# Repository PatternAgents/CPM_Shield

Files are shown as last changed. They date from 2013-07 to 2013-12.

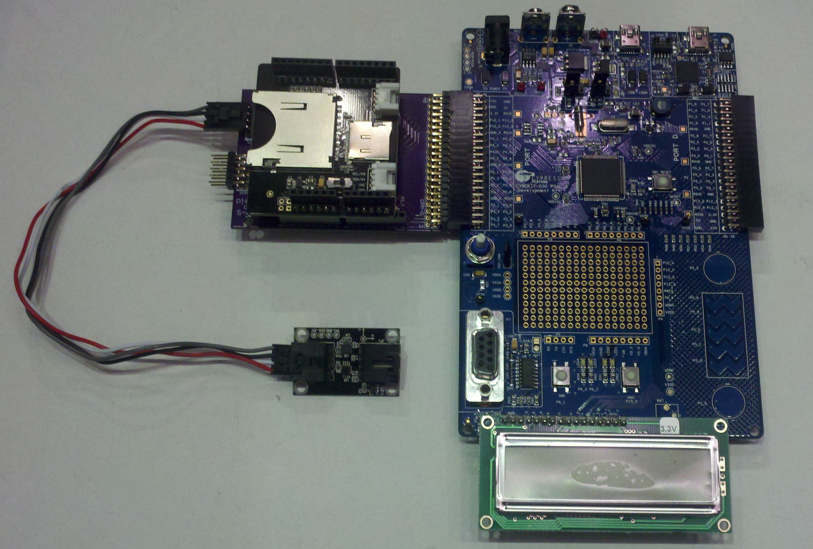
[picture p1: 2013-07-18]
CPM_Shield/images/final/hires/with_SD_shield.jpg

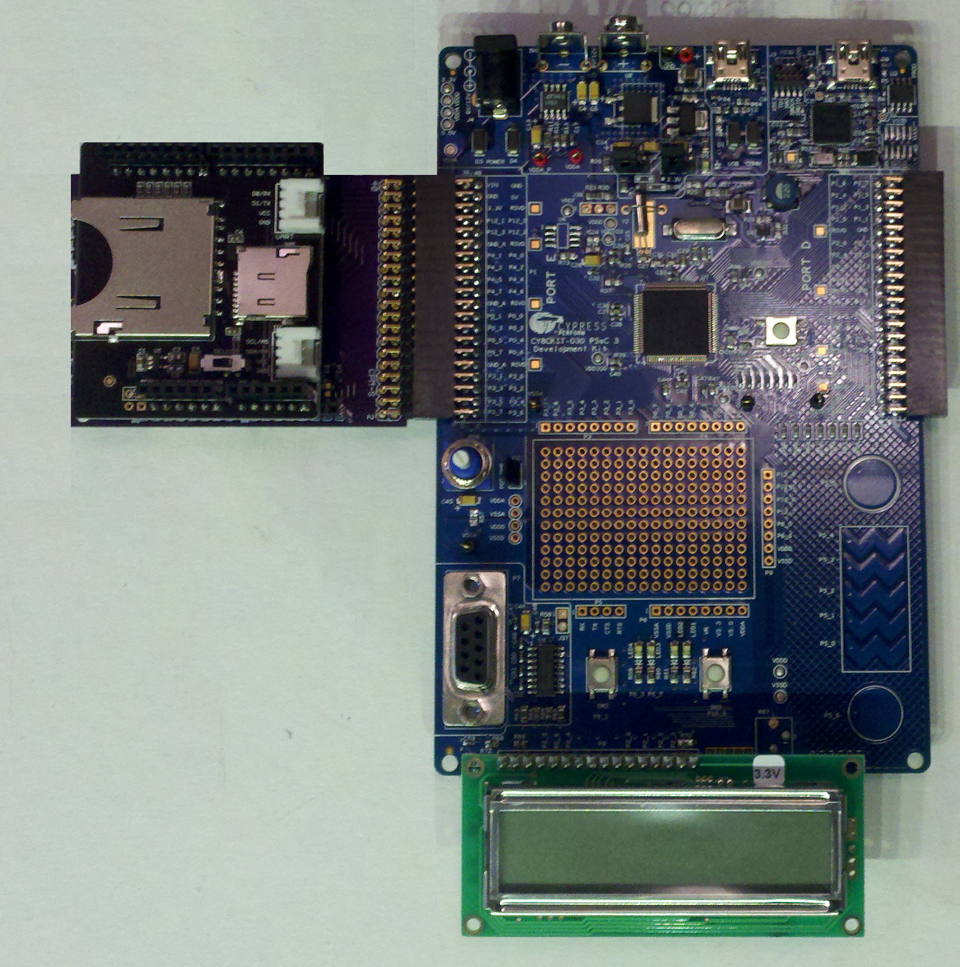
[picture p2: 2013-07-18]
CPM_Shield/images/final/hires/with_030_board_SD_CARD.jpg

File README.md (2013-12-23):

CPM Shield Adaptor
====================

PatternAgents CPM Shield Adaptor

[PatternAgents CPM Shield Adaptor  
*PatternAgents CPM Shield Adaptor*](http://www.patternagents.com/projects/CPM_Shield.html)

The "CPM Shield Adaptor" board is designed to enable Cypress PSoC development boards to utilize Arduino Shield peripherals.

The PatternAgents "CPM Shield Adaptor" board supports :

Cypress CY8CKIT-001 : (Supports up to three (3) "CPM Shield Adaptor")

Cypress CY8CKIT-030 : (Supports up to two (2) "CPM Shield Adaptor")

Cypress CY8CKIT-050 : (Supports up to two (2) "CPM Shield Adaptor")

Cypress CY3280-28xxx : (Supports one (1) "CPM Shield Adaptor")

Cypress CY3280-22x45 : (Supports one (1) "CPM Shield Adaptor")

(Not an Exhaustive list as more Cypress development boards are routinely released)

For information on the Arduino Shield Specification, see http://www.arduino.cc

[  
*Licensing CC BY-NC-SA 4.0*](http://creativecommons.org/licenses/by-nc-sa/4.0/)

PatternAgents uses the increasingly popular business model called "Dual Licensing" 
in which both the open source software distribution mechanism and traditional commercial software distribution models are combined.

Open Source Projects:        

If you are developing and distributing open source applications under the Creative Commons CC BY-NC-SA 4.0, 
as published by the Creative Commons Foundation, then you are free to use the PatternAgents hardware/software under the CC BY-NC-SA 4.0 license. 
Please note that CC BY-NC-SA 4.0 requires that all modifications to the original code as well as all Derivative Works 
must also be released under the terms of the CC BY-NC-SA 4.0 license.

Closed Source Projects:

If you are developing and distributing traditional closed source or commercial applications, 
you must purchase a PatternAgents commercial use license, 
which is specifically designed for users interested in retaining the proprietary status of their designs and code. 
All PatternAgents commercial licenses expressly supersede the CC BY-NC-SA 4.0 license. 
This means that when you license the PatternAgents software under a commercial license, 
you specifically do not use the software under the CC BY-NC-SA 4.0 license and therefore you are not subject to any of its terms.
        
If you would like to use our designs for your own personal or educational use, have at it! 

Our public design repository is available at <a href="https://github.com/patternagents">Github</a>.

If you would like to produce our designs for commercial use, or as products for sale, 
please contact us to arrange for a Commercial Use license. We have many other designs, 
as well as options and extras that are not released publicly. 
We will also customize designs, firmware, and software for a reasonable fee, just contact us to discuss your requirements.

THIS SOFTWARE IS PROVIDED BY THE CONTRIBUTORS "AS IS" AND WITHOUT ANY EXPRESS OR IMPLIED WARRANTIES, 
INCLUDING, BUT NOT LIMITED TO, THE IMPLIED WARRANTIES OF MERCHANTABILITY AND FITNESS FOR A PARTICULAR PURPOSE ARE DISCLAIMED. 
IN NO EVENT SHALL THE COPYRIGHT OWNER OR CONTRIBUTORS BE LIABLE FOR ANY DIRECT, INDIRECT, INCIDENTAL, SPECIAL, EXEMPLARY, 
OR CONSEQUENTIAL DAMAGES (INCLUDING, BUT NOT LIMITED TO, PROCUREMENT OF SUBSTITUTE GOODS OR SERVICES; LOSS OF USE, DATA, 
OR PROFITS; OR BUSINESS INTERRUPTION) HOWEVER CAUSED AND ON ANY THEORY OF LIABILITY, WHETHER IN CONTRACT, 
STRICT LIABILITY, OR TORT (INCLUDING NEGLIGENCE OR OTHERWISE) ARISING IN ANY WAY OUT OF THE USE OF THIS SOFTWARE, 
EVEN IF ADVISED OF THE POSSIBILITY OF SUCH DAMAGE. 

-------------------------------------------------------------------------------------------

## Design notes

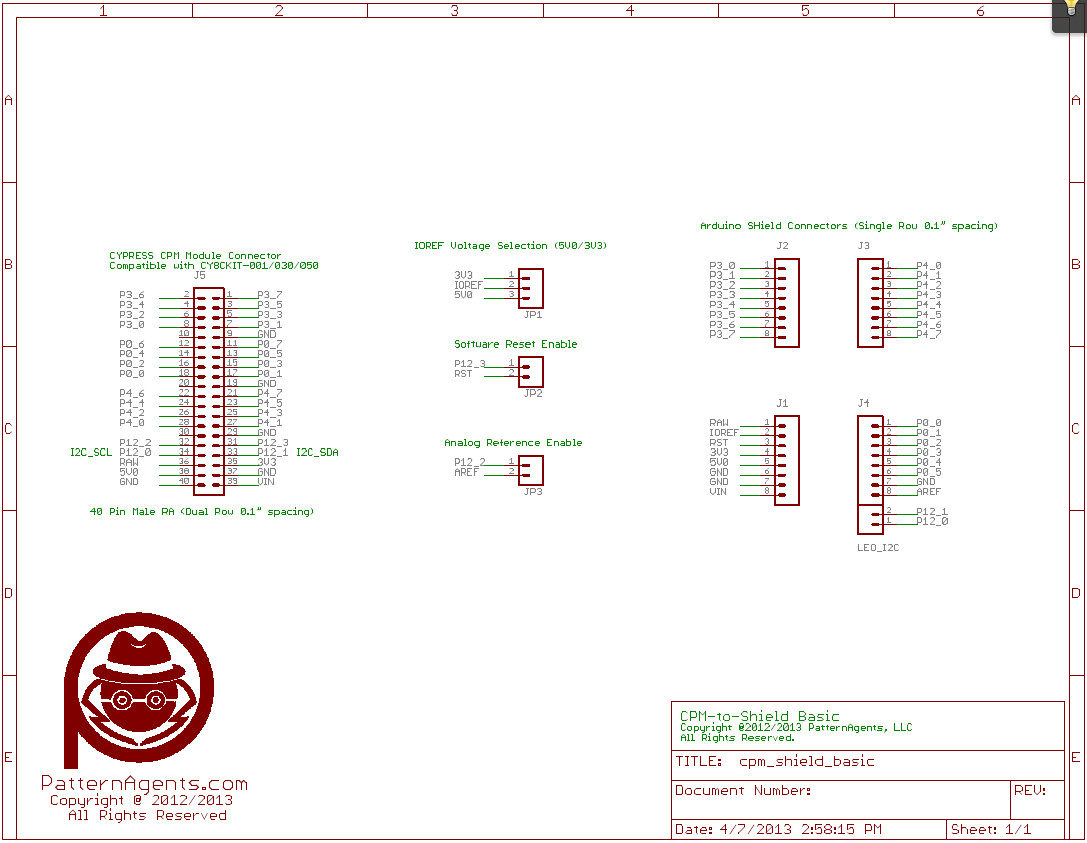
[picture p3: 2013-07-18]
CPM_Shield/hardware/cpm_shield_basic_SCH.jpg

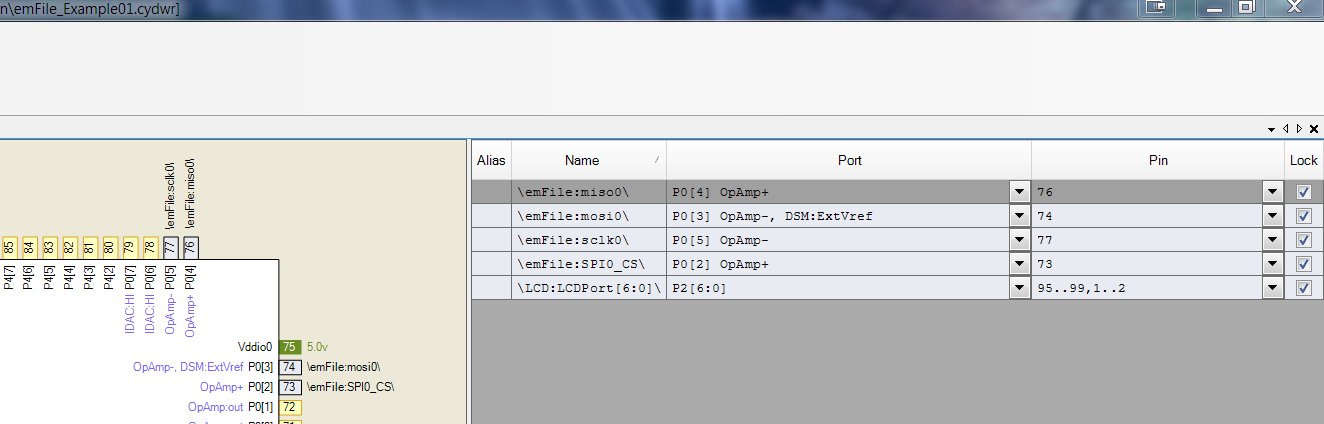
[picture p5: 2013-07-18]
CPM_Shield/images/final/hires/emFile_Example_cydwr.jpg

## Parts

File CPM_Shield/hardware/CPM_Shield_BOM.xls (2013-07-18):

CPM_to_Shield_Basic | Bill-of-Materials
CPM_to_Shield_Basic | Rev: 1.3 |  | REVISED | 2013-04-07
Description | Designator | Footprint | Quantity | Value | Vender | Substitution OK | VPN | Vendor2 | V2PN
CPM_to_Shield (Revison 1.3) | PCB |  | 1 |  |  |  | PCA:274A2012
8-Pin Header, Female | J1, J2, J3 | HDR8X1F | 3 | 8 | Samtec | Yes | SSW-108-01-T-S | Digikey | 929850-01-08-ND
10-Pin Header, Female | J4 | HDR10X1F | 1 | 10 | Samtec | Yes | SSW-110-01-T-S | Digikey | 732-2859-ND
Header, 40-Pin, Male, Right Angle | J5 | HDR40x2MRA | 1 | 40 | Samtec | Yes | TSW-120-08-T-D-RA | Digikey | 3M9485-ND
Header, 3-Pin, Male | JP1 | HDR3x1M | 1 | 3 | Samtec | Yes | TSW-103-05-T-S | Digikey | 609-3461-ND
Header, 2-Pin, Male | JP2,JP3 | HDR2x1M | 1 | 2 | Samtec | Yes | TSW-102-05-T-S | Digikey | 609-3500-ND
SPECIAL JUMPER INSTALLATION:
Jumper pins 1 and 2 "VOLT" on JP1 | SI-1 | JMP2x1 | 1 | 2-pos 0.1" | Digikey | Yes | A26228-ND | Digikey | 3M9580-ND
DO NOT POPULATE:
None.

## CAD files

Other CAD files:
CPM_Shield/eagleUp/cpm_to_shield_basic.skp

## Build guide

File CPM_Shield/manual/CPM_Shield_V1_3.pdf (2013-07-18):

CPM-to-Shield—Getting Started Guide

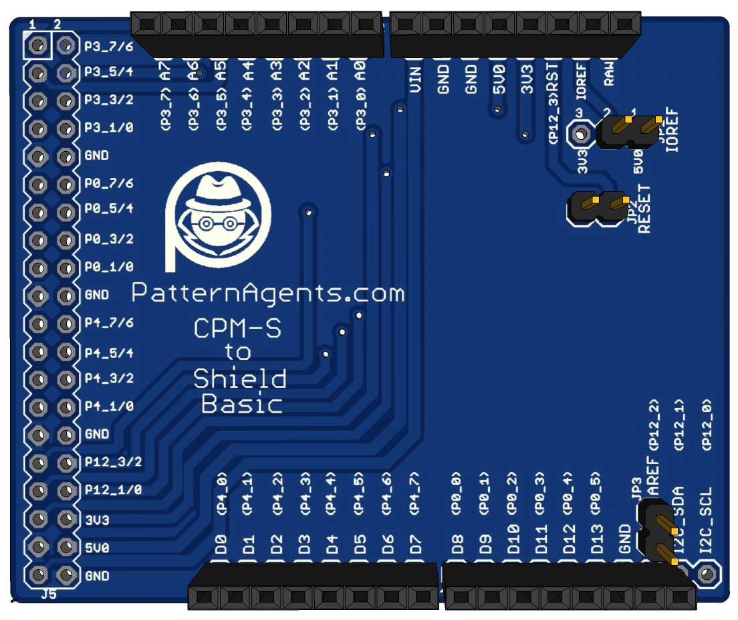
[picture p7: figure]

Page 1 | www.patternagents.com

## CPM-S to Arduino Shield Adaptor

## Getting Started Guide for the CPM Module Bus To Arduino Shield Adaptor

Copyright 2011, 2012, 2013 www.patternagents.com

http://www.patternagents.com/products.html

Revision 2.1.11
PCD #272A

Page 2 | www.patternagents.com

Congratulations on your purchase of the “CPM-S to Arduino Shield Adaptor” board!

The PatternAgents “CPM-S to Arduino Shield Adaptor” board has the following features :

1) CPM-S (Slave) Forty (40) Pin Male Connector.
2) Arduino “Leonardo” Extended, Stacking Shield Connector(s).
3) Support for Arduino “Leonardo” I2C Pins.
4) Configurable for 3.3V or 5.0V operation.
5) Configurable for Arduino programmable Reset (optional jumper).
6) Configurable for Arduino IOREF (optional jumper).
7) Configurable for Arduino AREF (optional jumper).

Overview :

The PatternAgents “CPM-S to Arduino Shield Adaptor” board is designed to enable products that incorporate a CPM-M (Master) Forty (40) Pin Female connector to utilize Arduino Shield boards. Current products that incorporate a CPM-M (Master) Forty (40) Pin Female connector, and are compatible with the PatternAgents “CPM-S to Arduino Shield Adaptor board are :

Cypress CY8CKIT-001 : (Supports up to three (3) “CPM-S to Arduino Shield Adaptors”) Cypress CY8CKIT-030 : (Supports up to two (2) “CPM-S to Arduino Shield Adaptors”) Cypress CY8CKIT-050 : (Supports up to two (2) “CPM-S to Arduino Shield Adaptors”) Cypress CY3280-28xxx : (Supports one (1) “CPM-S to Arduino Shield Adaptor”) Cypress CY3280-22x45 : (Supports one (1) “CPM-S to Arduino Shield Adaptor”)

(Not an Exhaustive list as more products are routinely released)

Getting Started :

To use the PatternAgents “CPM-S to Arduino Shield Adaptor” board simply plug it into a CPM-M (Master) socket and you are to start programming. You don’t have to worry about putting little jumper wires into the wrong spots, or having wires pull out when you move your board around.

NOTE: Always make sure the power is OFF, before adding or removing boards!

Stack-Thru Models (optional request):
As an option, PatternAgents “CPM-S to Arduino Shield Adaptor” boards can populated with “Stack-Thru” connectors, which allow Arduino Shields to be added to the top or bottom of the board stack.

NOTE: Always make sure the stacking pins don’t contact a metal surface (like a metal table).

Page 3 | www.patternagents.com

## CPM to Arduino Shield Adaptor

## Top View

Overview | 2
Getting Started | 2
CY8CKIT-030: SeeedStudio SDCard/Segger emFile Example Project | 4
Schematic and Layout | 8
Port “D” Pin Assignment | 10
Port “E” Pin Assignment | 5
Custom Configuration Jumpers | 12
Frequently Asked Questions (FAQ) | 14
CY3280-28xxx CapSense Example Project | 6

Contents :

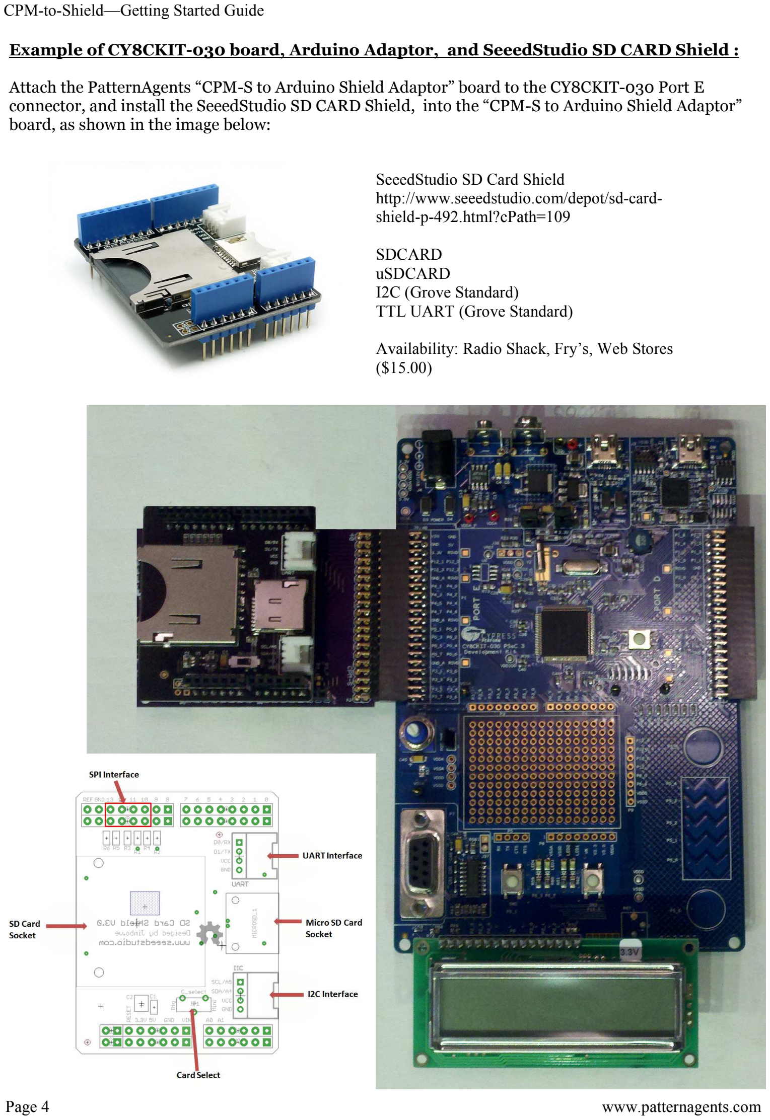
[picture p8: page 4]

Page 4 | www.patternagents.com

Example of CY8CKIT-030 board, Arduino Adaptor, and SeeedStudio SD CARD Shield :

Attach the PatternAgents “CPM-S to Arduino Shield Adaptor” board to the CY8CKIT-030 Port E connector, and install the SeeedStudio SD CARD Shield, into the “CPM-S to Arduino Shield Adaptor” board, as shown in the image below:

SeeedStudio SD Card Shield http://www.seeedstudio.com/depot/sd-cardshield-p-492.html?cPath=109

SDCARD
uSDCARD
I2C (Grove Standard)
TTL UART (Grove Standard)

Availability: Radio Shack, Fry’s, Web Stores ($15.00)

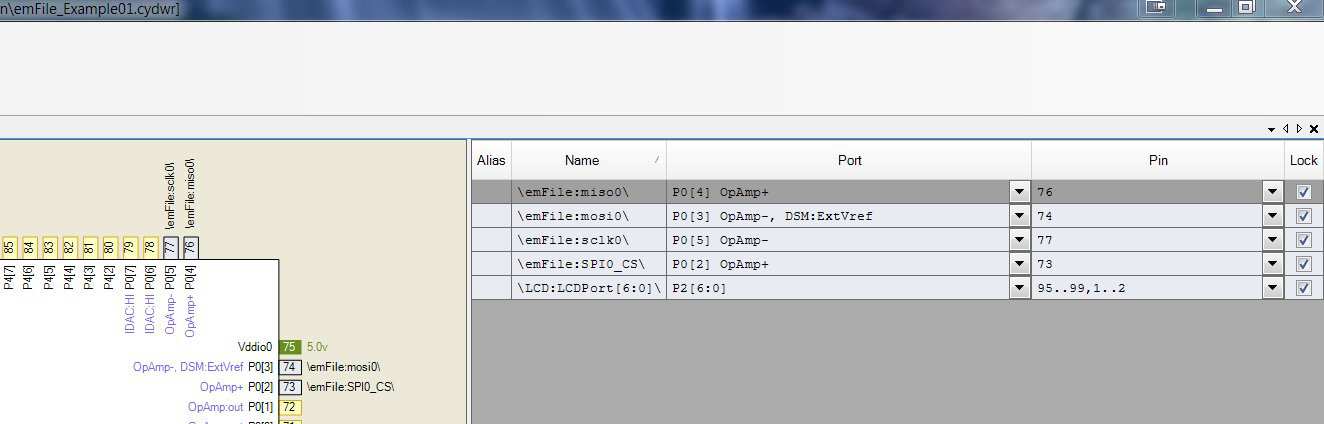
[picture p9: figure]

Page 5 | www.patternagents.com

PORT “E” I/O Assignment from CY8CKIT-030/050 board to SeeedStudio SDCARD Shield :

When the PatternAgents “CPM-S to Arduino Shield Adaptor” board is installed into Port E (Left Side) of a CY-C8CKIT-030/050 development kit, as shown to the left, and the SeeedStudio SDCARD Shield is installed, then default I/O Assignment is :

Arduino | Port E | Notes | SDCARD Shield
D10 | P0_2 | SPI0 SS | SDCARD Connector
D11 | P0_3 | SPI0 MOSI | SDCARD Connector
D12 | P0_4 | SPI0 MISO | SDCARD Connector
D13 | P0_5 | SPI0 SCK | SDCARD Connector

Example CY8CKIT-030 board and SeeedStudio SD CARD Shield
PSoC Creator Project (emFile_Example01) :

Utilizes Segger “emFile” file system component example project, “emFile_Example01” with (emFile_Example01.cydwr) pin assignment as :

NOTE: Read all project example installation directions (and follow the instructional video) at : http://www.cypress.com/?rID=58694
http://www.cypress.com/?docID=39399

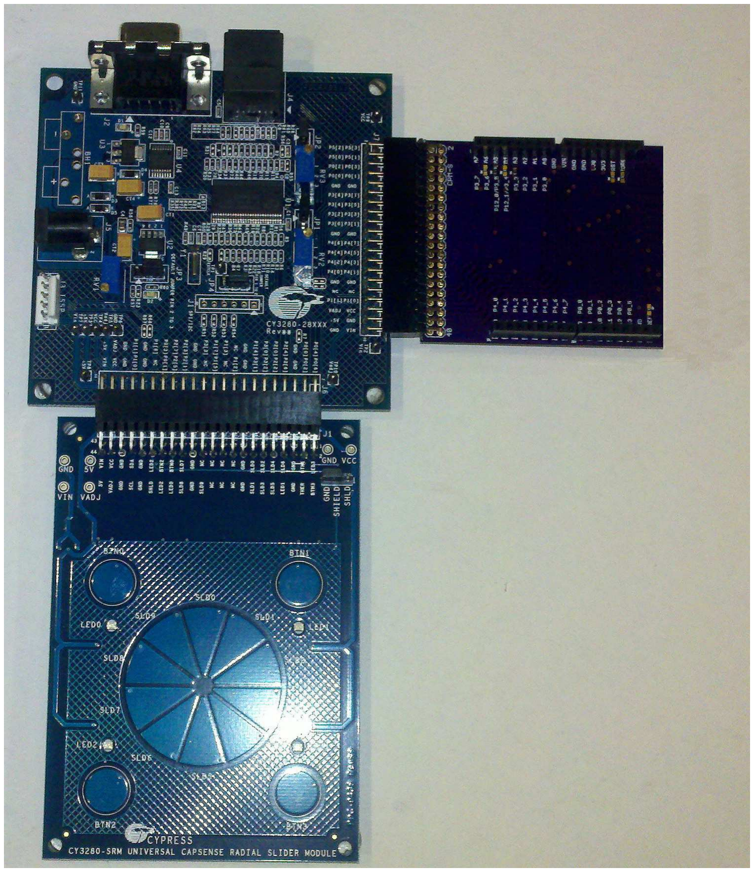
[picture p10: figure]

Page 6 | www.patternagents.com

Example for CY3280-28xxx (PSoC1 “NEON” family)
with CY3280-SRM (Capacitive Slider Radial Module),
Arduino shield adaptor, and Character LCD Shield:

Attach the PatternAgents “CPM-S to Arduino Shield Adaptor” board to the CY3280-28xxx
CPM connector. Then any Arduino compatible shield peripheral board can easily be attached to the “CPM-S to Arduino Shield Adaptor” board , as shown in the image below:

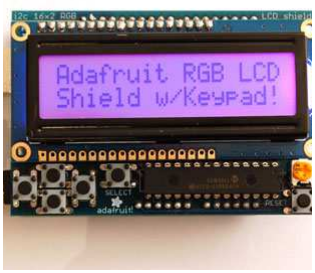
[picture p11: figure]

Page 7 | www.patternagents.com

PORT “E” I/O Assignment for CY3280-28xxx (PSoC1 “NEON” family)
with CY3280-SRM (Capacitive Slider Radial Module),
Arduino shield adaptor, and Character LCD Shield installed:

When the PatternAgents “CPM-S to Arduino Shield Adaptor” board is installed into Port E (Left Side) of a CY-C8CKIT-030/050 development kit, and a Character LCD Shield is attached,
the Shield I/O Assignment is as follows :
Arduino | Port E | Notes | LCD Shield
A0 | P0_0 | Analog Input 0 | Button 0
A1 | P0_1 | Analog Input 1 | Button 1
A2 | P0_2 | Analog Input 2 | Button 2
A3 | P0_3 | Analog Input 3 | Button 3
A4 | P5_0 | Analog Input 4 | Unused
A5 | P5_1 | Analog Input 5 | Unused
A6 | P5_2 | Analog Input 6 | Unused
A7 | P5_3 | Analog Input 7 | Unused
D0 | P4_0 | UART0 RX | LCD DB4
D1 | P4_1 | UART0 TX | LCD DB5
D2 | P4_2 | PWM0 | LCD DB6
D3 | P4_3 | PWM1 | LCD DB7
D4 | P4_4 | PWM2 | LCD EN
D5 | P4_5 | PWM3 | LCD RS
D6 | P4_6 | PWM4 | LCD RW
D7 | P4_7 | PWM5 | LCD LED
D8 | P3_0 | GPIO0 | Button 4
D9 | P3_1 | GPIO1 | Button 5
D10 | P3_2 | SPI0 SS | Unused
D11 | P3_3 | SPI0 MOSI | Unused
D12 | P3_4 | SPI0 MISO | Unused
D13 | P3_5 | SPI0 SCK | Unused
D14 | P1_0 | I2C_SDA | I2C0 SDA
D15 | P1_1 | I2C_SCL | I2C0 SCL

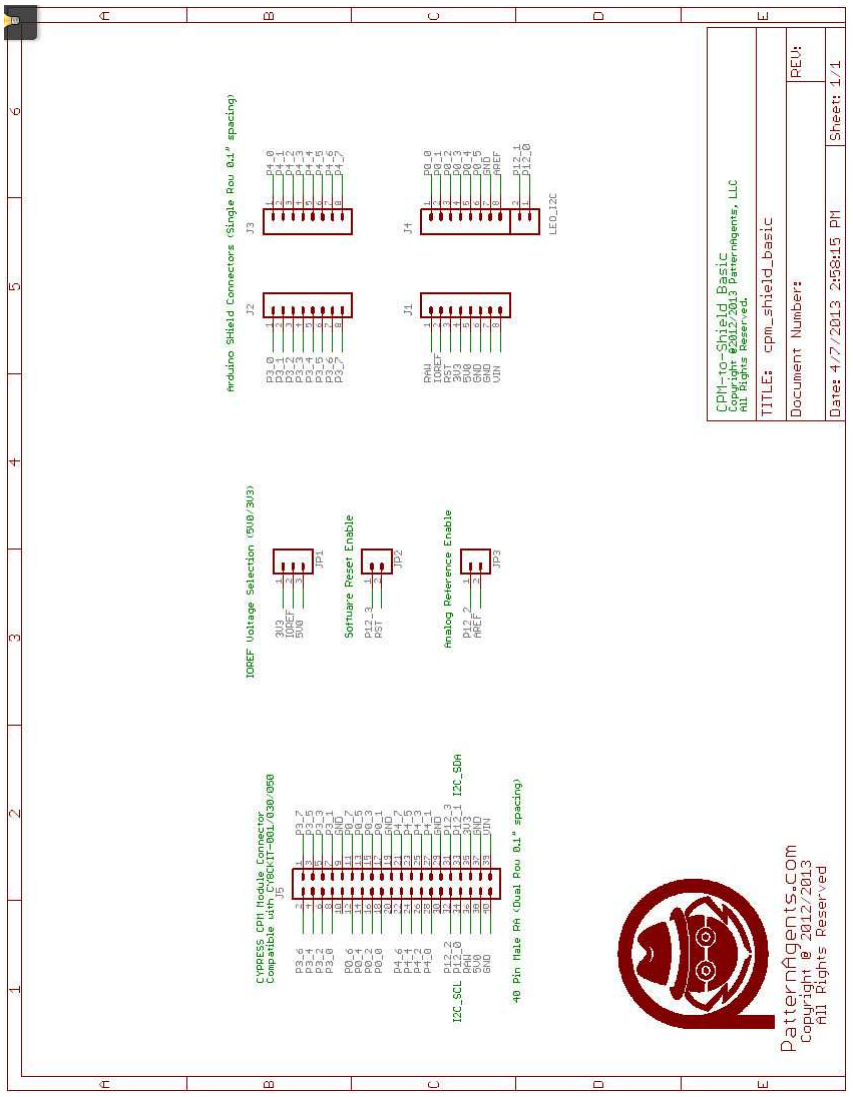
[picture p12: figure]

Page 8 | www.patternagents.com

Page 9 | www.patternagents.com

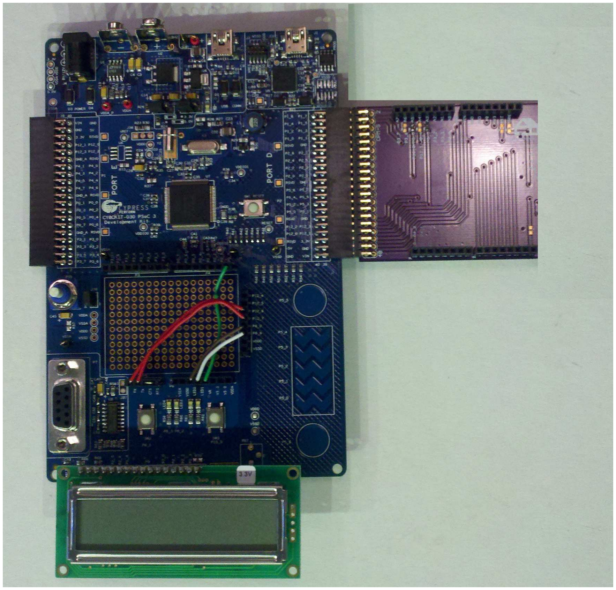
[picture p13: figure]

Page 10 | www.patternagents.com

PORT “D” I/O Assignment for Cypress CY8CKIT-030/050 Development Kits :

When the PatternAgents “CPM-S to Arduino Shield Adaptor” board is installed into Port D (Right Side) of a CY-C8CKIT-030/050 development kit, as shown below, the default I/O Assignment is :

Arduino | Port D | Notes
A0 | P1_0 | **JTAG SWDIO
A1 | P1_1 | **JTAG SWDCK
A2 | P1_2 | Analog Input
A3 | P1_3 | **JTAG SWO
A4 | P1_4 | Analog Input
A5 | P1_5 | Analog Input
A6 | P1_6 | Analog Input
A7 | P1_7 | Analog Input
D0 | P5_0 | UART0 RX
D1 | P5_1 | UART0 TX
D2 | P5_2 | PWM0
D3 | P5_3 | PWM1
D4 | P5_4 | PWM2
D5 | P5_5 | PWM3
D6 | P5_6 | PWM4
D7 | P5_7 | PWM5
D8 | P2_0 | **GPIO0
D9 | P2_1 | **GPIO1
D10 | P2_2 | **SPI1 SS
D11 | P2_3 | **SPI1 MOSI
D12 | P2_4 | **SPI1 MISO
D13 | P2_5 | **SPI1 SCK
D14 | P12_1 | I2C_SDA
D15 | P12_0 | I2C_SCL
AREF | P12_2 | ***Install JP3 (Zero Ohms)
RESET | P12_3 | ***Install JP2 (Zero Ohms)
Notes ** : | When using Port D Connector, by default P1 is used for JTAG and P2 for LCD.
These pins may need to reprogrammed to be able to be used properly.

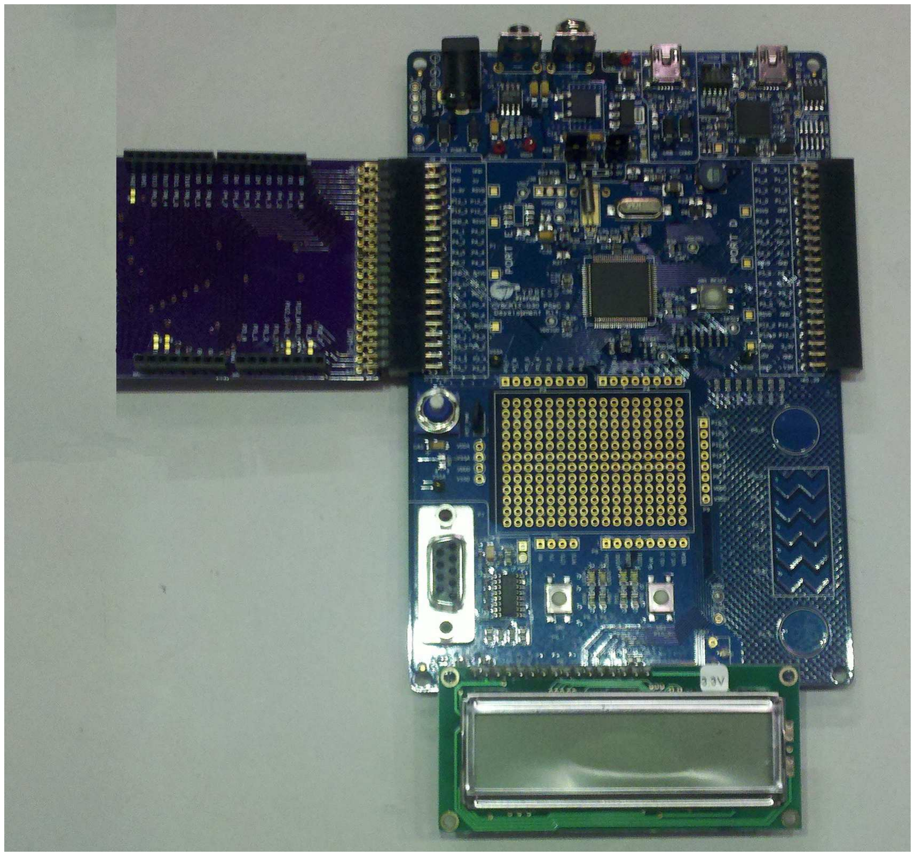
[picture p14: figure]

Page 11 | www.patternagents.com

PORT “E” I/O Assignment for Cypress CY8CKIT-030/050 Development Kits :

When the PatternAgents “CPM-S to Arduino Shield Adaptor” board is installed into Port E (Left Side) of a CY-C8CKIT-030/050 development kit, as shown below, the default I/O Assignment is :

Arduino | Port E | Notes
A0 | P3_0 | Analog Input
A1 | P3_1 | Analog Input
A2 | P3_2 | Analog Input
A3 | P3_3 | Analog Input
A4 | P3_4 | Analog Input
A5 | P3_5 | Analog Input
A6 | P3_6 | Analog Input
A7 | P3_7 | Analog Input
D0 | P4_0 | UART0 RX
D1 | P4_1 | UART0 TX
D2 | P4_2 | PWM0
D3 | P4_3 | PWM1
D4 | P4_4 | PWM2
D5 | P4_5 | PWM3
D6 | P4_6 | PWM4
D7 | P4_7 | PWM5
D8 | P0_0 | GPIO0
D9 | P0_1 | GPIO1
D10 | P0_2 | SPI1 SS
D11 | P0_3 | SPI1 MOSI
D12 | P0_4 | SPI1 MISO
D13 | P0_5 | SPI1 SCK
D14 | P12_1 | I2C_SDA
D15 | P12_0 | I2C_SCL
AREF | P12_2 | ***Install JP3 (Zero Ohms)
RESET | P12_3 | ***Install JP2 (Zero Ohms)
Notes ** : | The Port E Connector is the preferred connector for Analog Shield use,
and gives the most pins available that are not already used by the CY8CKIT-030/050 board.

Page 12 | www.patternagents.com

I/O Configuration :
The mapping of CPM-M (Master) I/O signals to Arduino Signals depends on which product you are using and which CPM-M (Master) socket you are plugged into. The default Legends printed on the the PatternAgents “CPM-S to Arduino Shield Adaptor” board (P0/P3/P4) assume that the board is plugged into PORT E of a CY8CKIT-030/CY8CKIT-050 board; which is the most common usage case. If you plug the PatternAgents “CPM-S to Arduino Shield Adaptor” board into a different CPM-M (Master) socket you will need to use the schematic on the last page of this document to determine your actual I/O signal assignment and configuration.

Arduino I/O Voltage Configuration :
The Cypress CY8CKIT-xxx boards have the ability to configure I/O signals for different voltage levels, and can be configured for either 3.3V or 5.0V volt levels. It is important to determine if your Arduino Shield requires 3.3V or 5.0V volt levels, and configure your CY8CKIT-xxx board correctly. Refer to the manual for your CPM-M (Master) board for the correct voltage settings.

NOTE: Always make sure voltages are set correctly for your Arduino shield or you can damage it.

RESET Control Mode (optional Configuration) :

In the default configuration, the jumper is not installed, as inadvertent operation could result;
the Arduino Bus Connector might be held in “Reset” state and might not operate correctly. If a programmable hardware reset is required, then install a jumper in JP2.
Arduino | CPM-S | Jumper
RESET | P12-3(SIO) | JP2 Installed

NOTE: For most purposes you need not change this configuration.

AREF Control Mode (optional Configuration) :

In the default configuration, the jumper is not installed, as inadvertent operation could
result ; the Arduino Bus Connector could receive an incorrect analog reference voltage and might not operate correctly. If an Analog hardware reference voltage is required, then install a jumper in Jp3.
Arduino | CPM-S | Jumper
AREF | P12-2(SIO) | JP3 Installed

NOTE: For most purposes you need not change this configuration.

IOREF Control Mode (optional Configuration) :

In the default configuration, the jumper is installed for 5.0V Arduino Shields. The IOREF hardware pin indicates what voltage level the peripheral shield is operating with.

Arduino | CPM-S | Jumper
IOREF | 5.0V | JP1 –1 to 2
IOREF | 3.3V | JP1 –2 to 3

Page 13 | www.patternagents.com

(This page intentionally left blank)

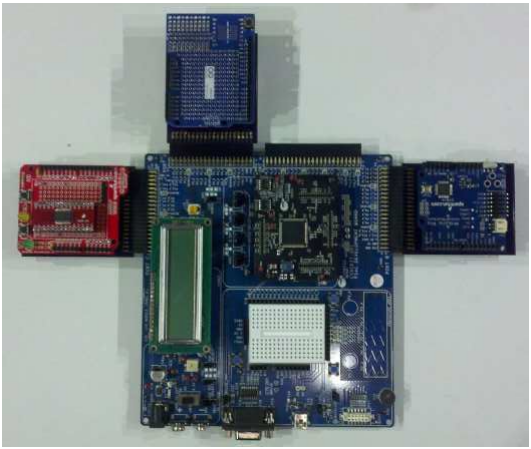
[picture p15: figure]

Page 14 | www.patternagents.com

FAQ :

1) Does the PatternAgents “CPM-S to Arduino Shield Adaptor” board have any “active “ components?

No. The CPM-S to Arduino Shield Adaptor” board is completely passive, and only rearranges signals from the development board to the Ardunio socket/board, with as little degradation as possible.

2) Can I use multiple PatternAgents “CPM-S to Arduino Shield Adaptor” boards on a single development kit base board?

Yes. You can often install multiple, “CPM-S to Arduino Shield Adaptor” boards, but you may not get every pin supported, as some pins on different development boards may map to either unimplemented pins or to pins already used by an onboard peripheral, such as the LCD display, capacitive touch buttons, LEDs, Prototyping Area, etc. May sure to verify your pin assignment in your project file for conflicts.

FAQ (continued) :

3) Can I use the “CPM-S to Arduino Shield Adaptor” with an “Arduino” CPU Board?

Yes. Any “Host” Arduino CPU board can be connected on the top/bottom side of the “CPM-S to Arduino Shield Adaptor” Board depending on what connector you install (i.e. female only, or stack-through connectors). This allows for multi-CPU/multi-processor/ multiple architecture (i.e. big/little) configurations.

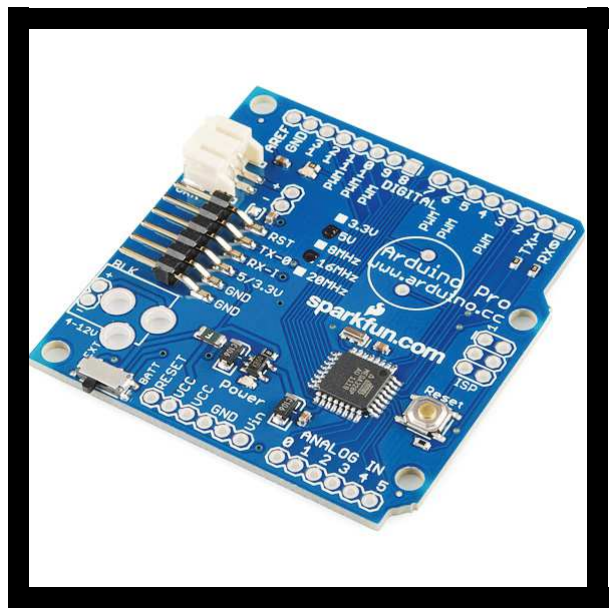
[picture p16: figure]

4) Can I use the “CPM-S to Arduino Shield Adaptor” with “Arduino” prototyping supplies ?

Yes. Any Arduino prototyping board can be connected on the top/bottom side of the “CPM-S to Ardu ino Shield Adaptor” Board depending on what connectors you install (i.e. male/female only, or stack- through).

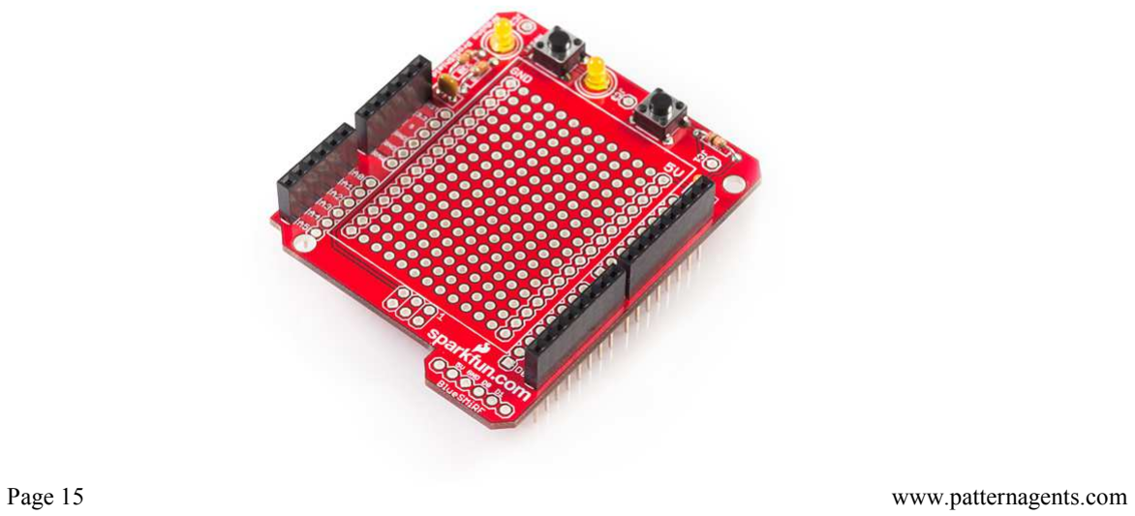
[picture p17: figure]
Page 15; www.patternagents.com

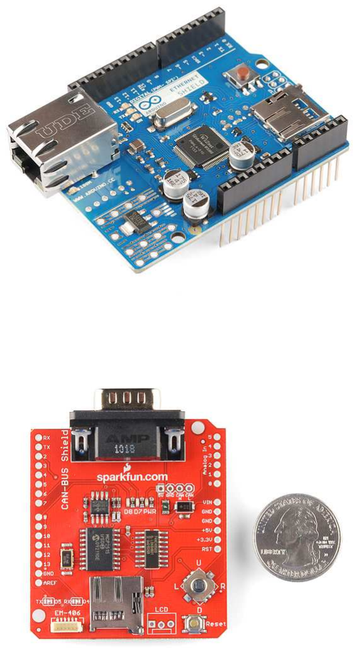
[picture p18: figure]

Page 16 | www.patternagents.com
5) Can I use the “CPM-S to Arduino Shield Adaptor” with other “Arduino” shields ?

Yes. (Almost) any Arduino shield board can be connected on the top/bottom side of
the “CPM-S to Arduino Shield Adaptor” Board depending on what connectors you install (i.e. male/female only, or stack-through)

Arduino Ethernet Shield :

Image from :
https://www.sparkfun.com/products/9026

Arduino CAN-BUS Shield :

Image from :
https://www.sparkfun.com/products/10039

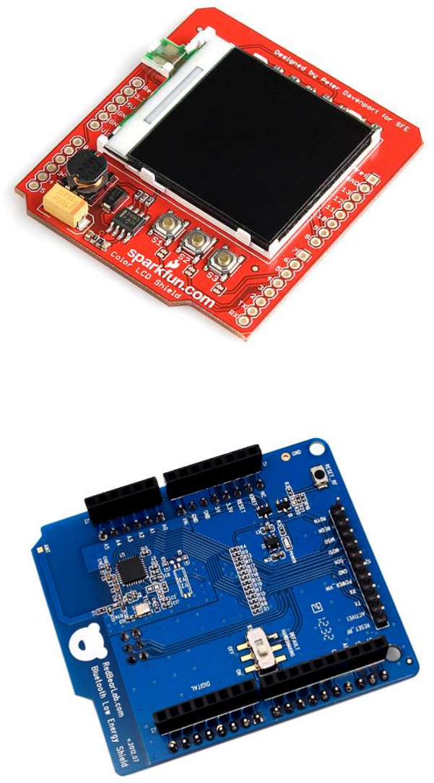
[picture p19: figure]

Page 17 | www.patternagents.com

Arduino Color LCD Shield :

Image from :
https://www.sparkfun.com/products/9363

provides an easy method of connecting the popular Nokia 6100 LCD to your PSoC.

Arduino BlueTooth LE Shield :

Image from :
https://www.seedstudio.com

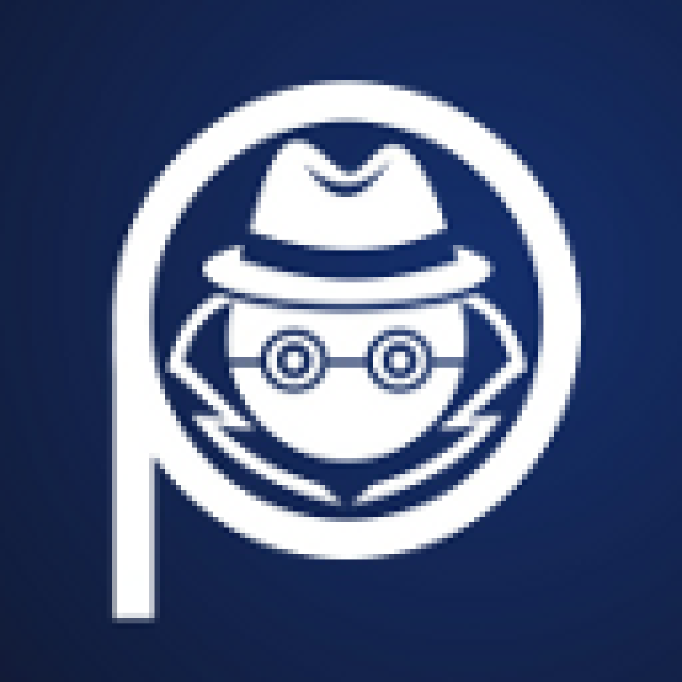
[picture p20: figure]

Page 18 | www.patternagents.com Copyright 2011, 2012, 2013 www.patternagents.com

# PatternAgents provides community and commerce for electronics designers so that they can collaborate using shared

design patterns, practices, and resources; connect with others in the industry, conceptualize and create new ideas,

# commercialize their designs, and keep up

on the latest technologies and concepts.

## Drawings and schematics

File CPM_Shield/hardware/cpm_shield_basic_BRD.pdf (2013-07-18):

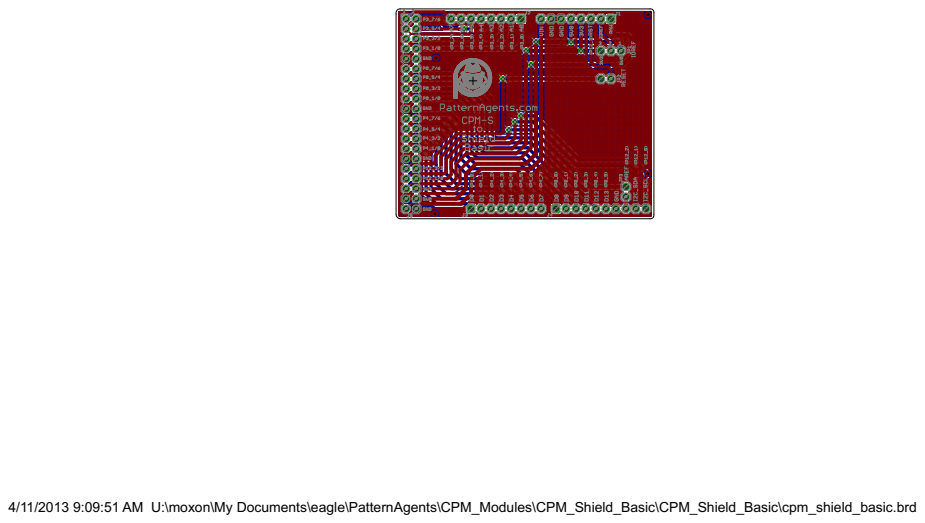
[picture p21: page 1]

4/11/2013 9:09:51 AM U:\moxon\My Documents\eagle\PatternAgents\CPM_Modules\CPM_Shield_Basic\CPM_Shield_Basic\cpm_shield_basic.brd

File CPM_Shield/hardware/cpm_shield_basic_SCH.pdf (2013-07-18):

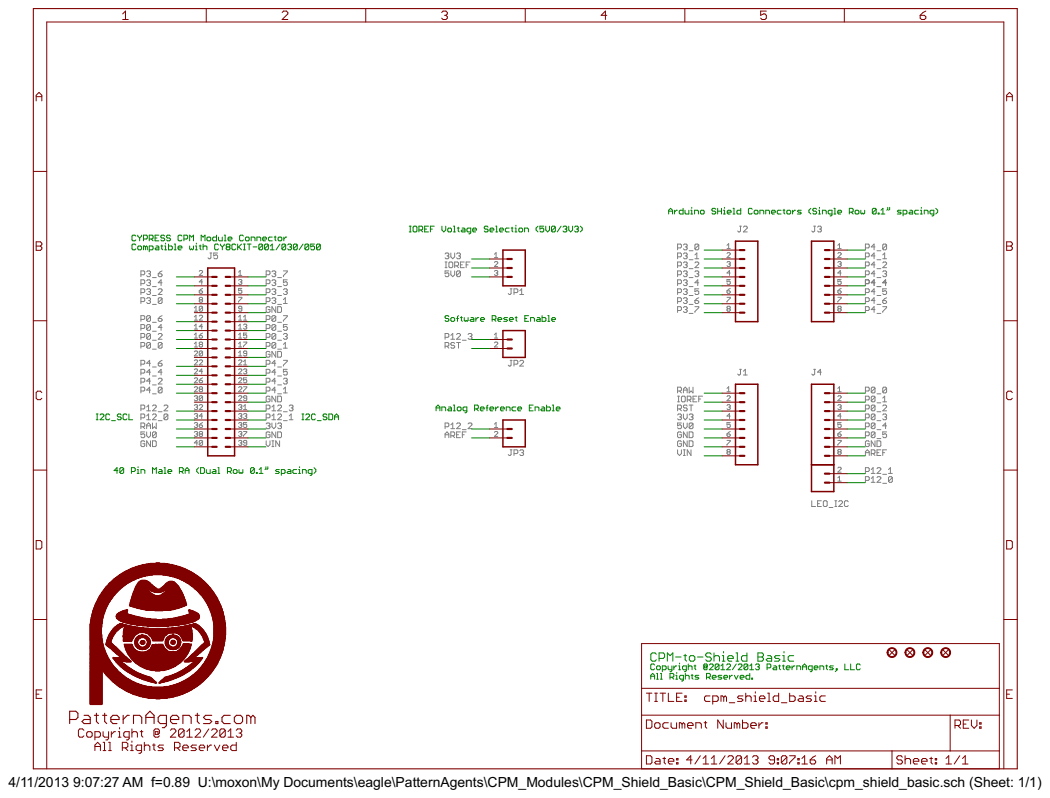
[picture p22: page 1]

4/11/2013 9:07:27 AM f=0.89 U:\moxon\My Documents\eagle\PatternAgents\CPM_Modules\CPM_Shield_Basic\CPM_Shield_Basic\cpm_shield_basic.sch (Sheet: 1/1)

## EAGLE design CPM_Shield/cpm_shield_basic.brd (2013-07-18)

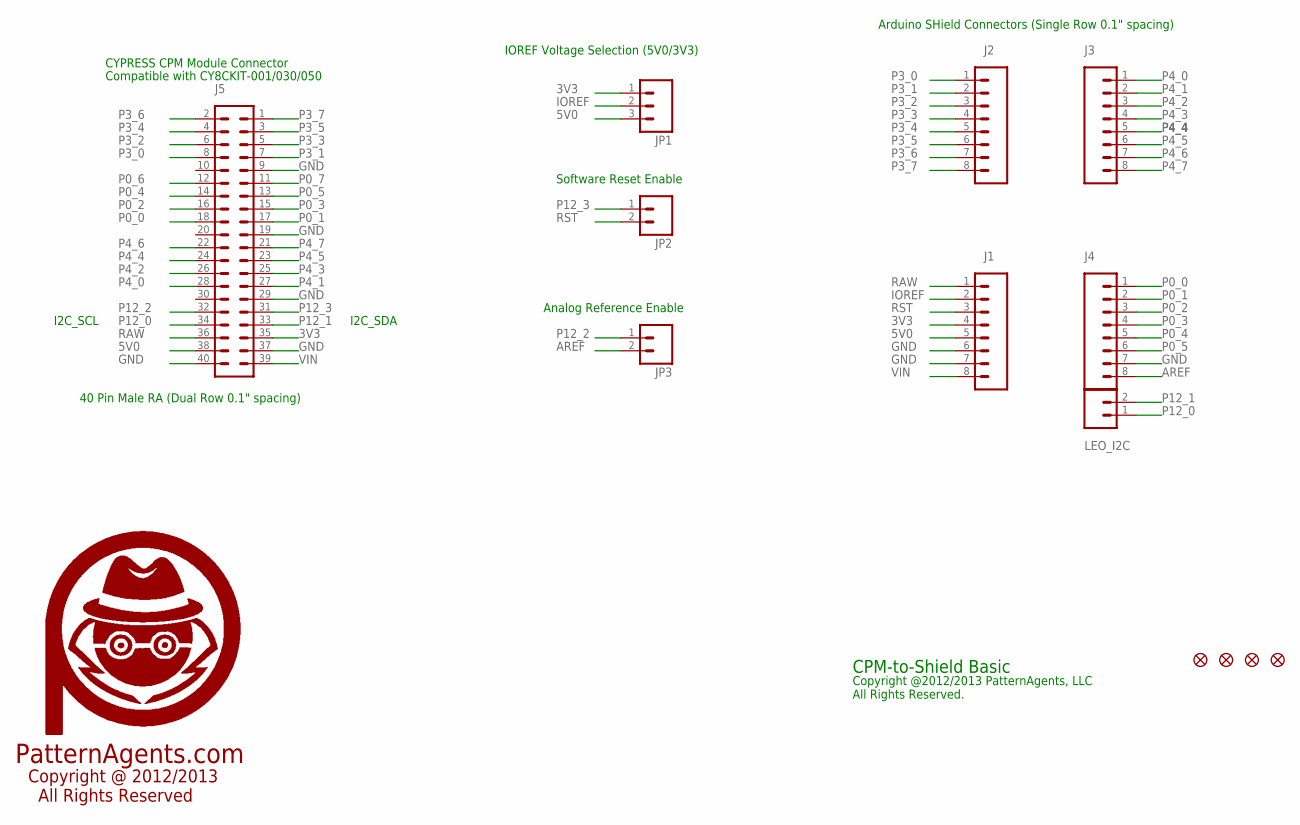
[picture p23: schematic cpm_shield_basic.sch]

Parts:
J1, J2, J3, J4: SAMTEC; 1X08
J5: SULLINS_SCS; MA20-2
JP1: M03PS; M03
JP2, JP3: M02PS; MA02
JP4, JP5, JP6, JP7: FIDUCIAL1.5X3; FIDUCIAL-1.5X3
LEO_I2C: M02PS; MA02
U$3: LOGO_PA_AGENTLARGE; LOGO_PA_AGENT_LARGE

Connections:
3V3: J1.4, J5.35, JP1.1
5V0: J1.5, J5.38, JP1.3
AREF: J4.8, JP3.2
GND: J1.6, J1.7, J4.7, J5.9, J5.19, J5.29, J5.37, J5.40
IOREF: J1.2, JP1.2
P0_0: J4.1, J5.18
P0_1: J4.2, J5.17
P0_2: J4.3, J5.16
P0_3: J4.4, J5.15
P0_4: J4.5, J5.14
P0_5: J4.6, J5.13
P0_6: J5.12
P0_7: J5.11
P3_0: J2.1, J5.8
P3_1: J2.2, J5.7
P3_2: J2.3, J5.6
P3_3: J2.4, J5.5
P3_4: J2.5, J5.4
P3_5: J2.6, J5.3
P3_6: J2.7, J5.2
P3_7: J2.8, J5.1
P4_0: J3.1, J5.28
P4_1: J3.2, J5.27
P4_2: J3.3, J5.26
P4_3: J3.4, J5.25
P4_4: J3.5, J5.24
P4_5: J3.6, J5.23
P4_6: J3.7, J5.22
P4_7: J3.8, J5.21
P12_0: J5.34, LEO_I2C.1
P12_1: J5.33, LEO_I2C.2
P12_2: J5.32, JP3.1
P12_3: J5.31, JP2.1
RAW: J1.1, J5.36
RST: J1.3, JP2.2
VIN: J1.8, J5.39

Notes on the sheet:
40 Pin Male RA (Dual Row 0.1" spacing)
CYPRESS CPM Module Connector
Compatible with CY8CKIT-001/030/050
Arduino SHield Connectors (Single Row 0.1" spacing)
I2C_SDA
I2C_SCL
IOREF Voltage Selection (5V0/3V3)
Software Reset Enable
Analog Reference Enable
CPM-to-Shield Basic
Copyright @2012/2013 PatternAgents, LLC All Rights Reserved.
PatternAgents.com
Copyright @ 2012/2013 All Rights Reserved

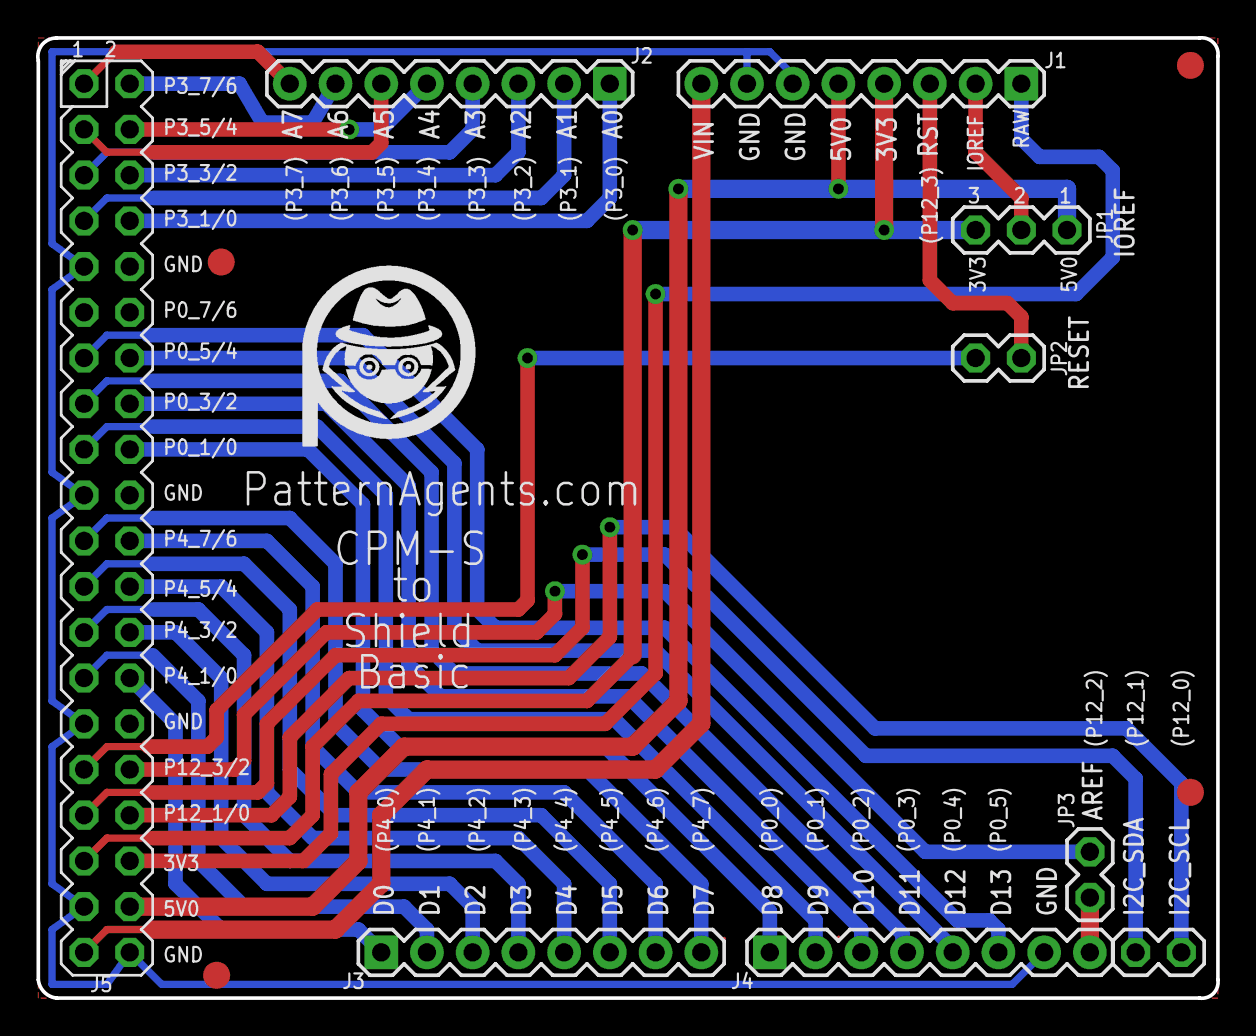
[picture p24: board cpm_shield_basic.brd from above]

Board: 2 copper layers, 65.6 x 53.4 mm, 15 parts (1 on the bottom side), 34 nets.

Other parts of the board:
U$2: LOGO_PA_AGENT_LARGE

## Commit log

2013-07-18 add Eagle design files
    [CPM_Shield_BOM.xls, CPM_Shield_Basic.skp, cpm_shield_basic.brd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]
2013-07-22 reduce png file sizes
    [CPM_Shield_Basic.skp]
